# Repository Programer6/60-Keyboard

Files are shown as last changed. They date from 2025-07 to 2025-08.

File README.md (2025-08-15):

# 60%-Keyboard

Design for 60% keyboard with KMK firmware because I wanted a compact, minimal layout that saves space without sacrificing functionality. Full-sized keyboards felt bulky for my setup! This is my first keyboard, which I designed, so I wanted to keep think simple (no QMK, ofc)

# PCB
- The PCB's size is
- 61x key default 60% Layout!
- 2x Rotary Encoder
- 2 screens!

## Images

| Schematic                 |
| ------------------------- |
| Screenshot 2025-07-21 at 5 22 16 PM |
| Screenshot 2025-07-21 at 5 22 35 PM |

| PCB                   |
| --------------------- |
| Screenshot 2025-07-21 at 5 23 27 PM |

| Case                  |
| --------------------- |
| Screenshot 2025-08-15 at 2 25 50 PM |
| Screenshot 2025-08-04 at 1 43 16 PM
|

## BOM 
| Name | Qty | Final Price | Link |
| :--- | :-- | :--- | :--- |
| Cherry Profile PBT Keycaps | 1 | 17 | [Link](https://www.aliexpress.com/item/1005009109030179.html) |
| EC11s Rotary Encoder Code 5pin | | 8 | [Link](https://www.aliexpress.us/item/1005008610645902.html) |
| Knob | 2 | 6 |Preint Legend|
| OLED Module 1 | 1 | 4 | [Link](https://www.aliexpress.com/item/1005007038294972.html) |
| OLED Module 2 | 1 | 4 | |
| Gateron EF Grayish | 70 | 22 | Will buy myself [Link](https://www.aliexpress.us/item/1005006358112479.html) |
| Plate Mount Stabilizers | 9 | 9 | [Link](https://www.aliexpress.us/item/1005006528731543.html) |
| m3 16 mm | 10 | 3 | [Link](https://www.aliexpress.us/item/32810872544.html) |
| M3 25 mm | 10 | 3 | [Link](https://www.aliexpress.us/item/32810872544.html) |
| PCB | 44 | 40 | |
| Raspberry Pi Pico | 6 | 6 | [Link](https://www.aliexpress.us/item/1005007661444023.html) |
| Poron Gasket Strip | | 4 | [Link](https://www.aliexpress.com/item/1005003607093794.html) |
| M3(OD4.2mm) Heatset Insert | 25 | 2 | [Link](https://www.aliexpress.us/item/1005003582355741.html) |
| Keyboard Case | 1 | 5 | Print Legend |
| Diode 1N4148 Through | 80 | 1.3 | [Link](https://www.aliexpress.us/item/4000142272546.html) |

## Total Pricing
140$ - High estimate price rounded up! & buffer

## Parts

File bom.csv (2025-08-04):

Name | Qty | Final Price | Link
Cherry Profile PBT Keycaps | 1 | 17 | https://www.aliexpress.com/item/1005009109030179.html
EC11s Rotary Encoder Code 5pin |  | 8 | https://www.aliexpress.us/item/1005008610645902.html
Knob | 2 | 6 | https://www.aliexpress.us/item/1005008610645902.html
OLED Module 1 | 1 | 4 | https://www.aliexpress.com/item/1005007038294972.html
OLED Module 2 | 1 | 4
Gateron EF Grayish | 70 | 22 | https://www.aliexpress.us/item/1005006358112479.html
Plate Mount Stabilizers | 9 | 9 | https://www.aliexpress.us/item/1005006528731543.html
m3 16 mm | 10 | 3 | https://www.aliexpress.us/item/32810872544.html
M3 25 mm | 10 | 3 | https://www.aliexpress.us/item/32810872544.html
PCB | 44 | 40
Raspberry Pi Pico | 6 | 6 | https://www.aliexpress.us/item/1005007661444023.html
Poron Gasket Strip |  | 4 | https://www.aliexpress.com/item/1005003607093794.html
M3(OD4.2mm) Heatset Insert | 25 | 2 | https://www.aliexpress.us/item/1005003582355741.html
Keyboard Case | 1 | 5 | Print Legend
Diode 1N4148 Through | 80 | 1.3 | https://www.aliexpress.us/item/4000142272546.html

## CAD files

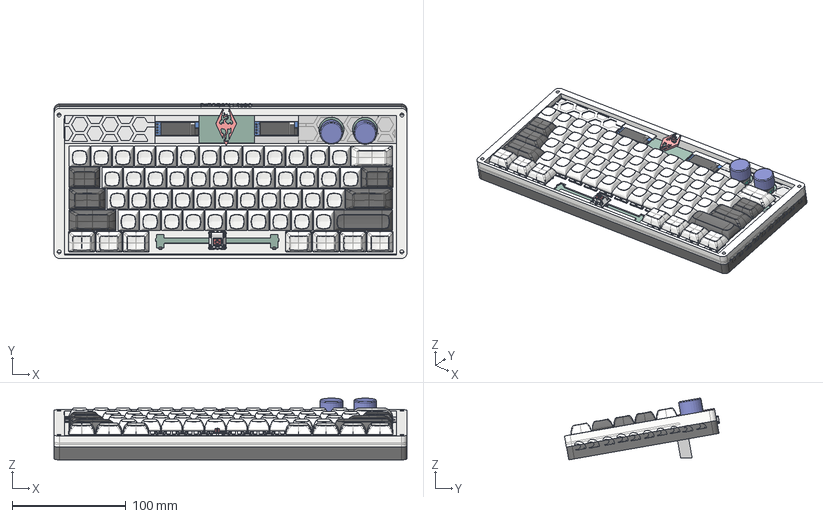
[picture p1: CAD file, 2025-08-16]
CAD/keyboard-v2 v4.step
310.0 x 136.3 x 54.2 mm
PCB, Raspberry Pi Pico-R3
MicroUSB Port, Raspberry Pi Pico-R3
RP2040 Microcontroller, Raspberry Pi Pico-R3
SW1, Tact Switch, Raspberry Pi Pico-R3
D1, Diode, Schottky, Raspberry Pi Pico-R3
D2, QSME-C194, LED, Raspberry Pi Pico-R3
L1, Inductor, Raspberry Pi Pico-R3
U2, RT6150B-33GQW, Buck Boost Converter, Raspberry Pi Pico-R3
U3, W25Q16JVUXIQ, Serial NOR Flash 16 Mbit, Raspberry Pi Pico-R3
Q1, MOSFET, DMG1012T, Raspberry Pi Pico-R3
X1, X12M000000S096, 12 Mhz Crystal Resonator, Raspberry Pi Pico-R3
SMD Resistor, Configurable, Raspberry Pi Pico-R3_R1
SMD Resistor, Configurable, Raspberry Pi Pico-R3_R2
SMD Resistor, Configurable, Raspberry Pi Pico-R3_R3
SMD Resistor, Configurable, Raspberry Pi Pico-R3_R4
SMD Resistor, Configurable, Raspberry Pi Pico-R3_R5
SMD Resistor, Configurable, Raspberry Pi Pico-R3_R6
SMD Resistor, Configurable, Raspberry Pi Pico-R3_R7
SMD Resistor, Configurable, Raspberry Pi Pico-R3_R8
SMD Resistor, Configurable, Raspberry Pi Pico-R3_R9
SMD Resistor, Configurable, Raspberry Pi Pico-R3_R10
SMD Resistor, Configurable, Raspberry Pi Pico-R3_R11
SMD Resistor, Configurable, Raspberry Pi Pico-R3_R12
SMD Resistor, Configurable, Raspberry Pi Pico-R3_R13
SMD Resistor, Configurable, Raspberry Pi Pico-R3_R14
SMD Resistor, Configurable, Raspberry Pi Pico-R3_R15
SMD Capacitor, Configurable, Raspberry Pi Pico-R3_C1
SMD Capacitor, Configurable, Raspberry Pi Pico-R3_C2
SMD Capacitor, Configurable, Raspberry Pi Pico-R3_C3
SMD Capacitor, Configurable, Raspberry Pi Pico-R3_C4
SMD Capacitor, Configurable, Raspberry Pi Pico-R3_C5
SMD Capacitor, Configurable, Raspberry Pi Pico-R3_C6
SMD Capacitor, Configurable, Raspberry Pi Pico-R3_C7
SMD Capacitor, Configurable, Raspberry Pi Pico-R3_C8
SMD Capacitor, Configurable, Raspberry Pi Pico-R3_C9
SMD Capacitor, Configurable, Raspberry Pi Pico-R3_C10
SMD Capacitor, Configurable, Raspberry Pi Pico-R3_C11
SMD Capacitor, Configurable, Raspberry Pi Pico-R3_C12
SMD Capacitor, Configurable, Raspberry Pi Pico-R3_C13
SMD Capacitor, Configurable, Raspberry Pi Pico-R3_C14
SMD Capacitor, Configurable, Raspberry Pi Pico-R3_C15
SMD Capacitor, Configurable, Raspberry Pi Pico-R3_C16
SMD Capacitor, Configurable, Raspberry Pi Pico-R3_C17
SMD Capacitor, Configurable, Raspberry Pi Pico-R3_C18
(Unsaved) (1) x 61
MX Mount v1 x 46
ѽת±ძǷ (1) x 2
Volume Knob x 2
OLED_0.91_128x32_2 x 2
Pin Header 4 x 1 TH 2.54mm Pitch x 2
RESC-0603 x 26
2SD0601A x 2
keycap5 x 2
R_0805_2012Metric x 2
QFN-28-1EP_6x6mm_P0.65mm_EP4.25x4.25mm
keycap x 7
DSA 2.75u
keycap3
keycap2 x 2
keycap4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

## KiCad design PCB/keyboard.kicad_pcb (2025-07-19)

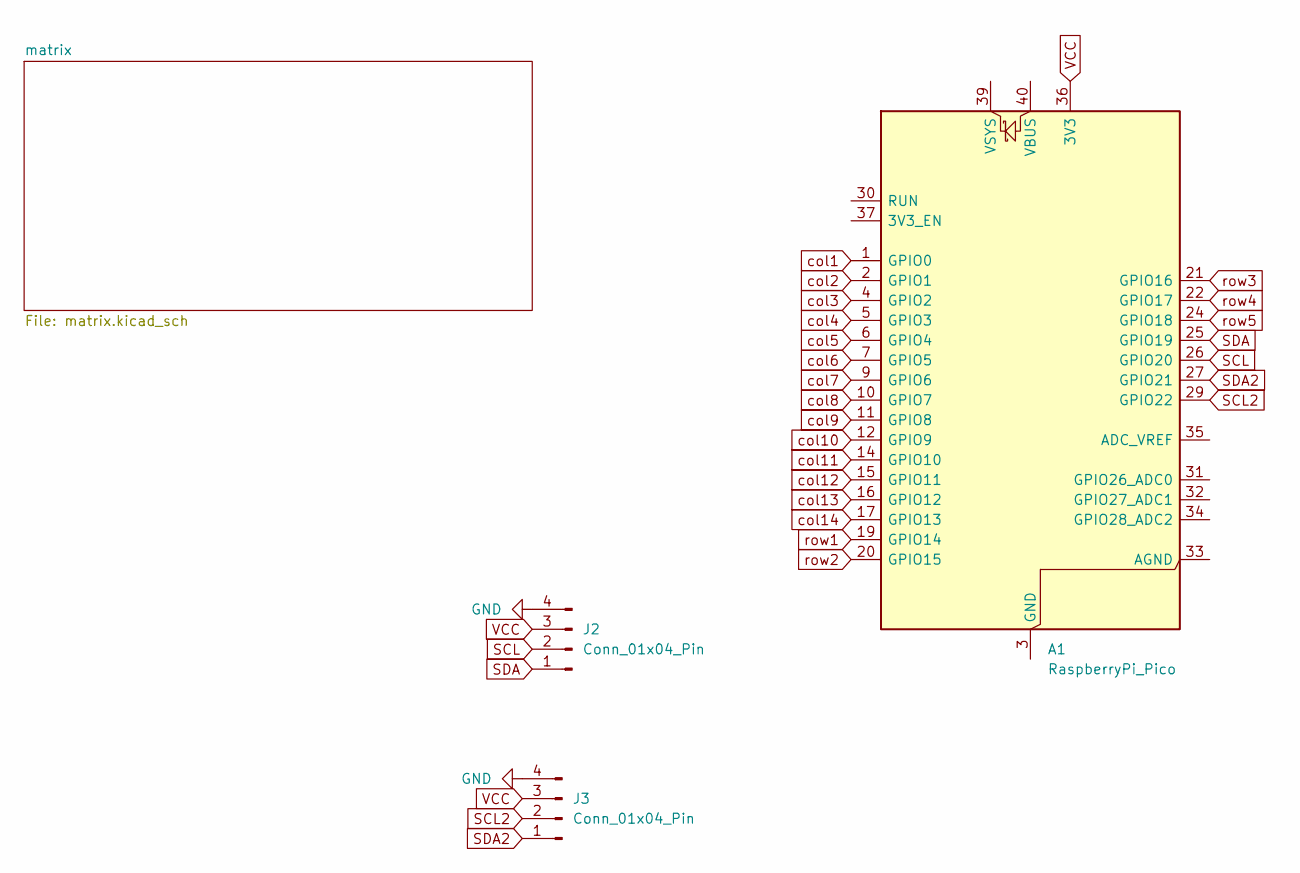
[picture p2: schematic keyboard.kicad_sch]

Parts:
A1: RaspberryPi_Pico; RaspberryPi_Pico_Common_Unspecified
J2, J3: Conn_01x04_Pin; SSD1306-0.91-OLED-4pin-128x32

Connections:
GND: J2.4, J3.4; also elsewhere on the board
unnamed: A1.3 (GND), A1.8 (GND), A1.13 (GND), A1.18 (GND), A1.23 (GND), A1.28 (GND), A1.38 (GND)
SCL: A1.26 (GPIO20), J2.2
SCL2: A1.29 (GPIO22), J3.2
SDA: A1.25 (GPIO19), J2.1
SDA2: A1.27 (GPIO21), J3.1
VCC: A1.36 (3V3), J2.3, J3.3
col1: A1.1 (GPIO0); also elsewhere on the board
col2: A1.2 (GPIO1); also elsewhere on the board
col3: A1.4 (GPIO2); also elsewhere on the board
col4: A1.5 (GPIO3); also elsewhere on the board
col5: A1.6 (GPIO4); also elsewhere on the board
col6: A1.7 (GPIO5); also elsewhere on the board
col7: A1.9 (GPIO6); also elsewhere on the board
col8: A1.10 (GPIO7); also elsewhere on the board
col9: A1.11 (GPIO8); also elsewhere on the board
col10: A1.12 (GPIO9); also elsewhere on the board
col11: A1.14 (GPIO10); also elsewhere on the board
col12: A1.15 (GPIO11); also elsewhere on the board
col13: A1.16 (GPIO12); also elsewhere on the board
col14: A1.17 (GPIO13); also elsewhere on the board
row1: A1.19 (GPIO14); also elsewhere on the board
row2: A1.20 (GPIO15); also elsewhere on the board
row3: A1.21 (GPIO16); also elsewhere on the board
row4: A1.22 (GPIO17); also elsewhere on the board
row5: A1.24 (GPIO18); also elsewhere on the board

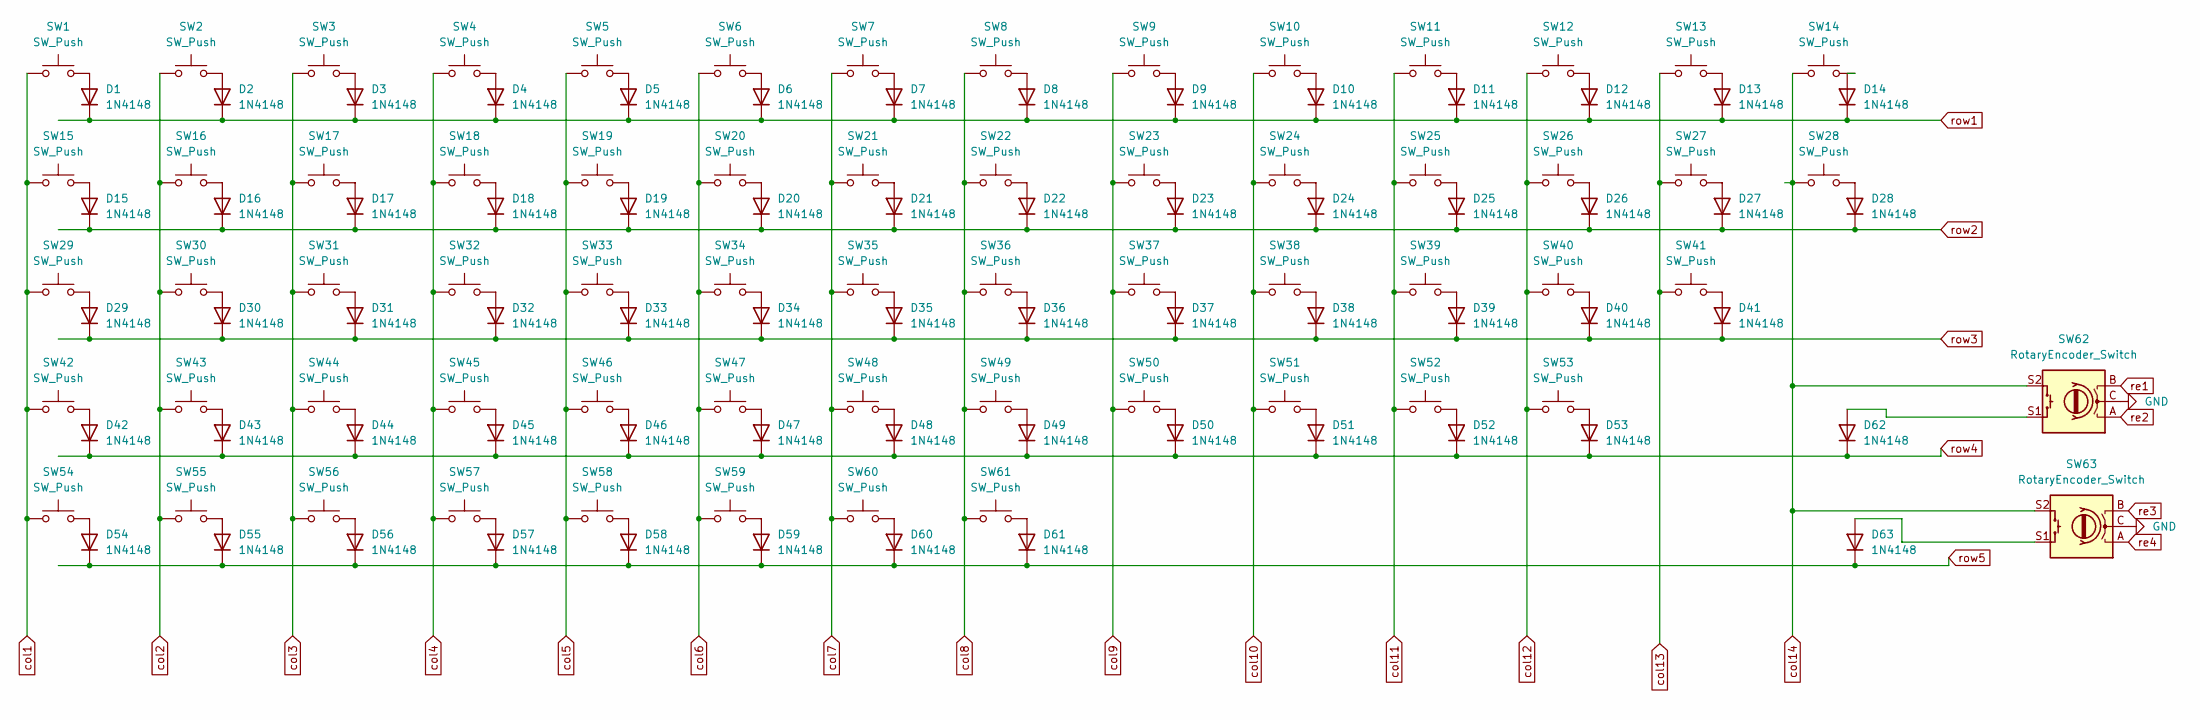
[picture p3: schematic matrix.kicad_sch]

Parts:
D1, D2, D3, D4, D5, D6, D7, D8, D9, D10, D11, D12, D13, D14, D15, D16, D17, D18, D19, D20, D21, D22, D23, D24, D25, D26, D27, D28, D29, D30, D31, D32, D33, D34, D35, D36, D37, D38, D39, D40, D41, D42, D43, D44, D45, D46, D47, D48, D49, D50, D51, D52, D53, D54, D55, D56, D57, D58, D59, D60, D61, D62, D63: 1N4148; D_DO-35_SOD27_P7.62mm_Horizontal
SW1, SW2, SW3, SW4, SW5, SW6, SW7, SW8, SW9, SW10, SW11, SW12, SW13, SW16, SW17, SW18, SW19, SW20, SW21, SW22, SW23, SW24, SW25, SW26, SW27, SW30, SW31, SW32, SW33, SW34, SW35, SW36, SW37, SW38, SW39, SW40, SW43, SW44, SW45, SW46, SW47, SW48, SW49, SW50, SW51, SW52: SW_Push; SW_Cherry_MX_1.00u_PCB
SW14: SW_Push; SW_Cherry_MX_2.00u_PCB
SW15, SW28: SW_Push; SW_Cherry_MX_1.50u_PCB
SW29: SW_Push; SW_Cherry_MX_1.75u_PCB
SW41, SW42: SW_Push; SW_Cherry_MX_2.25u_PCB
SW53: SW_Push; SW_Cherry_MX_2.75u_PCB
SW54, SW55, SW56, SW58, SW59, SW60, SW61: SW_Push; SW_Cherry_MX_1.25u_PCB
SW57: SW_Push; SW_Cherry_MX_6.25u_PCB
SW62, SW63: RotaryEncoder_Switch; RotaryEncoder_Alps_EC11E-Switch_Vertical_H20mm_CircularMoun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

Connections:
GND: SW62.C, SW63.C; also elsewhere on the board
unnamed: D1.2 (A), SW1.2
unnamed: D2.2 (A), SW2.2
unnamed: D3.2 (A), SW3.2
unnamed: D4.2 (A), SW4.2
unnamed: D5.2 (A), SW5.2
unnamed: D6.2 (A), SW6.2
unnamed: D7.2 (A), SW7.2
unnamed: D8.2 (A), SW8.2
unnamed: D9.2 (A), SW9.2
unnamed: D10.2 (A), SW10.2
unnamed: D11.2 (A), SW11.2
unnamed: D12.2 (A), SW12.2
unnamed: D13.2 (A), SW13.2
unnamed: D14.2 (A), SW14.2
unnamed: D15.2 (A), SW15.2
unnamed: D16.2 (A), SW16.2
unnamed: D17.2 (A), SW17.2
unnamed: D18.2 (A), SW18.2
unnamed: D19.2 (A), SW19.2
unnamed: D20.2 (A), SW20.2
unnamed: D21.2 (A), SW21.2
unnamed: D22.2 (A), SW22.2
unnamed: D23.2 (A), SW23.2
unnamed: D24.2 (A), SW24.2
unnamed: D25.2 (A), SW25.2
unnamed: D26.2 (A), SW26.2
unnamed: D27.2 (A), SW27.2
unnamed: D28.2 (A), SW28.2
unnamed: D29.2 (A), SW29.2
unnamed: D30.2 (A), SW30.2
unnamed: D31.2 (A), SW31.2
unnamed: D32.2 (A), SW32.2
unnamed: D33.2 (A), SW33.2
unnamed: D34.2 (A), SW34.2
unnamed: D35.2 (A), SW35.2
unnamed: D36.2 (A), SW36.2
unnamed: D37.2 (A), SW37.2
unnamed: D38.2 (A), SW38.2
unnamed: D39.2 (A), SW39.2
unnamed: D40.2 (A), SW40.2
unnamed: D41.2 (A), SW41.2
unnamed: D42.2 (A), SW42.2
unnamed: D43.2 (A), SW43.2
unnamed: D44.2 (A), SW44.2
unnamed: D45.2 (A), SW45.2
unnamed: D46.2 (A), SW46.2
unnamed: D47.2 (A), SW47.2
unnamed: D48.2 (A), SW48.2
unnamed: D49.2 (A), SW49.2
unnamed: D50.2 (A), SW50.2
unnamed: D51.2 (A), SW51.2
unnamed: D52.2 (A), SW52.2
unnamed: D53.2 (A), SW53.2
unnamed: D54.2 (A), SW54.2
unnamed: D55.2 (A), SW55.2
unnamed: D56.2 (A), SW56.2
unnamed: D57.2 (A), SW57.2
unnamed: D58.2 (A), SW58.2
unnamed: D59.2 (A), SW59.2
unnamed: D60.2 (A), SW60.2
unnamed: D61.2 (A), SW61.2
unnamed: D62.2 (A), SW62.S1
unnamed: D63.2 (A), SW63.S1
col1: SW1.1, SW15.1, SW29.1, SW42.1, SW54.1; also elsewhere on the board
col2: SW2.1, SW16.1, SW30.1, SW43.1, SW55.1; also elsewhere on the board
col3: SW3.1, SW17.1, SW31.1, SW44.1, SW56.1; also elsewhere on the board
col4: SW4.1, SW18.1, SW32.1, SW45.1, SW57.1; also elsewhere on the board
col5: SW5.1, SW19.1, SW33.1, SW46.1, SW58.1; also elsewhere on the board
col6: SW6.1, SW20.1, SW34.1, SW47.1, SW59.1; also elsewhere on the board
col7: SW7.1, SW21.1, SW35.1, SW48.1, SW60.1; also elsewhere on the board
col8: SW8.1, SW22.1, SW36.1, SW49.1, SW61.1; also elsewhere on the board
col9: SW9.1, SW23.1, SW37.1, SW50.1; also elsewhere on the board
col10: SW10.1, SW24.1, SW38.1, SW51.1; also elsewhere on the board
col11: SW11.1, SW25.1, SW39.1, SW52.1; also elsewhere on the board
col12: SW12.1, SW26.1, SW40.1, SW53.1; also elsewhere on the board
col13: SW13.1, SW27.1, SW41.1; also elsewhere on the board
col14: SW14.1, SW28.1, SW62.S2, SW63.S2; also elsewhere on the board
re1: SW62.B
re2: SW62.A
re3: SW63.B
re4: SW63.A
row1: D1.1 (K), D2.1 (K), D3.1 (K), D4.1 (K), D5.1 (K), D6.1 (K), D7.1 (K), D8.1 (K), D9.1 (K), D10.1 (K), D11.1 (K), D12.1 (K), D13.1 (K), D14.1 (K); also elsewhere on the board
row2: D15.1 (K), D16.1 (K), D17.1 (K), D18.1 (K), D19.1 (K), D20.1 (K), D21.1 (K), D22.1 (K), D23.1 (K), D24.1 (K), D25.1 (K), D26.1 (K), D27.1 (K), D28.1 (K); also elsewhere on the board
row3: D29.1 (K), D30.1 (K), D31.1 (K), D32.1 (K), D33.1 (K), D34.1 (K), D35.1 (K), D36.1 (K), D37.1 (K), D38.1 (K), D39.1 (K), D40.1 (K), D41.1 (K); also elsewhere on the board
row4: D42.1 (K), D43.1 (K), D44.1 (K), D45.1 (K), D46.1 (K), D47.1 (K), D48.1 (K), D49.1 (K), D50.1 (K), D51.1 (K), D52.1 (K), D53.1 (K), D62.1 (K); also elsewhere on the board
row5: D54.1 (K), D55.1 (K), D56.1 (K), D57.1 (K), D58.1 (K), D59.1 (K), D60.1 (K), D61.1 (K), D63.1 (K); also elsewhere on the board

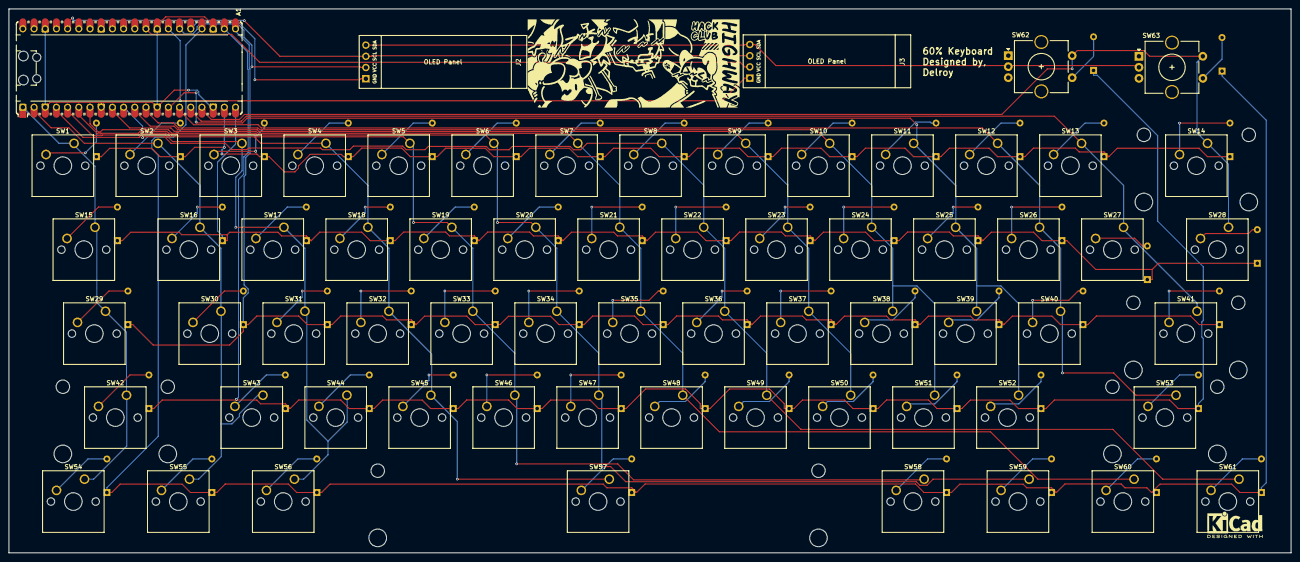
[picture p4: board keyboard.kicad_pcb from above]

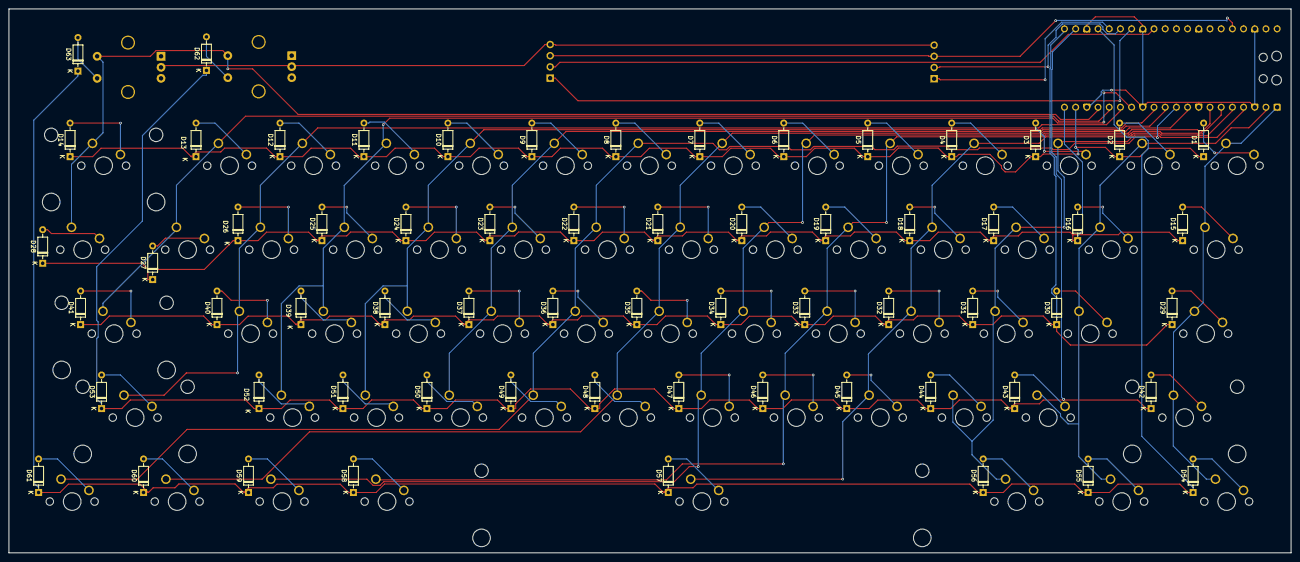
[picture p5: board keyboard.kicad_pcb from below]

Board: 2 copper layers, 290.9 x 123.4 mm, 129 parts (63 on the bottom side), 89 nets.

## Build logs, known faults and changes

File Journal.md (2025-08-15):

# 3D Printer Design: CAD & PCB Documentation
_Made by: @codelife / @programmer6_

| | |
|---|---|
| **Project Status** | Awaiting funding |
| **Total Time** |  30 Hours |
| **CAD Link** | https://a360.co/3TSTLiT |
| **Repository** | https://github.com/Programer6/60-Keyboard |

---

## June 18, 2025 - Schematic Design (3.5 hours)
I spent most of the day in KiCad laying out the schematic for the keyboard.

I designed a 5-row by 14-column key matrix. Each switch is paired with a 1N4148 diode to prevent "ghosting," an issue where unintended key presses are registered. I also added support for two rotary encoders (ideal for volume control or scrolling) and two I2C connectors for optional OLED screens. After double-checking all connections, the initial schematic is complete.

KiCad schematic of the key matrix with diodes

The plan is to use a Raspberry Pi Pico as the microcontroller. It's powerful, affordable, and has excellent community support, particularly with the KMK firmware I intend to use.

KiCad schematic of the Raspberry Pi Pico and its connections

Here are the other detailed views from the schematic:

KiCad schematic showing rotary encoder connections
KiCad schematic showing I2C connector details
KiCad schematic showing another view of the key matrix
KiCad schematic overview

---
## June 19, 2025 - Initial Component Placement (2.5 hours)
Started the initial placement of components on the PCB. I held off on routing the traces because I realized there were still a few things to update in the schematic, and I also want to add some custom silkscreen art.

Initial component placement in KiCad's PCB editor
Close-up of initial component placement

---
## June 20, 2025 - Schematic Revision & GPIO Expander (3 hours)
I started laying out the PCB today and immediately ran into a problem. While the Pi Pico has a lot of GPIO pins, my initial design used almost all of them, which was going to make routing the board a nightmare.

To fix this, I revised the schematic to include an **MCP23017 GPIO expander**. This significantly reduces the number of pins required on the Pico, freeing up space and making the layout much cleaner.

While I was at it, I also fixed the I2C connections. Thanks to a suggestion from **LemonGravy**, I've consolidated the entire I2C bus. The GPIO expander and the two OLED screen connectors (J1, J2) now share the same SCL and SDA lines, with the proper pull-up resistors added.

Revised schematic with the MCP23017 GPIO expander

---
## June 21, 2025 - PCB Routing (5 hours)
I spent the entire day routing the PCB in KiCad. The decision to use a GPIO expander yesterday really paid off, as it made the routing process much more manageable and resulted in a cleaner layout.

Here is the fully routed board:
Fully routed PCB in KiCad

---
## June 22, 2025 - 3D Visualization & Case Design (7 hours total)

#### 3D Models in KiCad (3 hours)
I added 3D models for all the components in KiCad. This provides a realistic 3D preview of the finished PCB, which is crucial for verifying component placement and clearances before designing the case.
3D view of the PCB in KiCad with all component models

#### 3D Printed Case Design (4 hours)
After finalizing the PCB, I exported the 3D model from KiCad and imported it into Fusion 360. I designed a simple and functional two-part case: a main body that holds the PCB and a top frame that acts as a switch plate and bezel.
3D model of the keyboard case designed in Fusion 360

---
## June 23, 2025 - Firmware and Documentation (8 hours total)

#### KMK Firmware (5 hours)
I spent the day writing the firmware for the keyboard using KMK, a powerful CircuitPython-based firmware. I configured the key matrix, rotary encoders, and the I2C bus for the OLED screens. The initial firmware is now functional and ready for flashing.

#### Documentation & BOM (3 hours)
Finalized the project documentation by creating the Bill of Materials (BOM), organizing all progress logs and images, and writing this README file to document the entire process.

Updated Keyboard after getting rejected:
Screenshot 2025-08-04 at 1 51 33 PM

 #### Got unofficial review from Taran the Idiot
-  Production folder had a file named production with no file type which I forgot to add so updated
-  Update BOM to use knob from printing Legion
- hugged the oleds a bit more in cad
- Update the journal and image in repo with the changes made!

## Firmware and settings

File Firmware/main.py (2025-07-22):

import board
import busio
import displayio
import terminalio
from adafruit_display_text import label
from adafruit_displayio_ssd1306 import SSD1306

from kmk.kmk_keyboard import KMKKeyboard
from kmk.keys import KC
from kmk.scanners import DiodeOrientation
from kmk.modules.layers import Layers
from kmk.modules.encoders import Encoders
from kmk.extensions.mcp23017 import MCP23017
from kmk.extensions.media_keys import MediaKeys
from kmk.extensions import Extension

class OledScreen(Extension):
    def __init__(self, i2c_bus):
        displayio.release_displays()

        try:
            display_bus_one = displayio.I2CDisplay(i2c_bus, device_address=0x3C)
            self.display_one = SSD1306(display_bus_one, width=128, height=32)
            self.group_one = displayio.Group()
            self.display_one.show(self.group_one)

            self.layer_label = label.Label(terminalio.FONT, text="Layer: 0", x=2, y=5)
            self.caps_label = label.Label(terminalio.FONT, text="CAPS", x=2, y=25)
            self.num_label = label.Label(terminalio.FONT, text="NUM", x=42, y=25)
            
            self.group_one.append(self.layer_label)
            self.group_one.append(self.caps_label)
            self.group_one.append(self.num_label)
        except (ValueError, RuntimeError):
            self.display_one = None

        try:
            display_bus_two = displayio.I2CDisplay(i2c_bus, device_address=0x3D)
            self.display_two = SSD1306(display_bus_two, width=128, height=64)
            self.group_two = displayio.Group()
            self.display_two.show(self.group_two)

            logo_label = label.Label(terminalio.FONT, text="-- My Keeb --", scale=2, x=10, y=30)
            self.group_two.append(logo_label)
        except (ValueError, RuntimeError):
            self.display_two = None

    def on_state_change(self, key, is_pressed, int_coord):
        if self.display_one:
            self.layer_label.text = f"Layer: {key.active_layers[0]}"
            self.caps_label.hidden = not key.caps_lock_status
            self.num_label.hidden = not key.num_lock_status

keyboard = KMKKeyboard()

keyboard.modules.append(Layers())
keyboard.modules.append(Encoders())
keyboard.extensions.append(MediaKeys())

i2c = busio.I2C(scl=board.GP9, sda=board.GP8)

oled_ext = OledScreen(i2c_bus=i2c)
keyboard.extensions.append(oled_ext)

mcp23017_ext = MCP23017(
    i2c=i2c,
    device_address=0x20,
    gp_int_a=None,
    gp_int_b=None,
)
keyboard.extensions.append(mcp23017_ext)

keyboard.col_pins = (
    board.GP0, board.GP1, board.GP2, board.GP3,
    board.GP4, board.GP5, board.GP6, board.GP7,
    board.GP10, board.GP11, board.GP12, board.GP13,
    board.GP14, board.GP15,
)
keyboard.row_pins = (
    mcp23017_ext.get_pin('GPB0'), mcp23017_ext.get_pin('GPB1'),
    mcp23017_ext.get_pin('GPB2'), mcp23017_ext.get_pin('GPB3'),
    mcp23017_ext.get_pin('GPB4'),
)
keyboard.diode_orientation = DiodeOrientation.COL2ROW

keyboard.encoder_handler.pins = (
    (board.GP16, board.GP17, None),
    (board.GP18, board.GP19, None),
)

FN = KC.MO(1)
_______ = KC.TRNS

keyboard.keymap = [
    [
        KC.GRAVE, KC.N1,    KC.N2,   KC.N3,    KC.N4,   KC.N5,   KC.N6,    KC.N7,   KC.N8,   KC.N9,    KC.N0,   KC.MINS,  KC.EQL,   KC.BSPC,
        KC.TAB,   KC.Q,     KC.W,    KC.E,     KC.R,    KC.T,    KC.Y,     KC.U,    KC.I,    KC.O,     KC.P,    KC.LBRC,  KC.RBRC,  KC.BSLS,
        KC.CAPS,  KC.A,     KC.S,    KC.D,     KC.F,    KC.G,    KC.H,    KC.J,    KC.K,    KC.L,     KC.SCLN, KC.QUOT,  KC.ENT,   KC.NO,
        KC.LSFT,  KC.Z,     KC.X,    KC.C,     KC.V,    KC.B,    KC.N,    KC.M,    KC.COMM, KC.DOT,   KC.SLSH, KC.RSFT,  KC.UP,    KC.NO,
        KC.LCTL,  KC.LGUI,  KC.LALT, KC.SPC,   KC.NO,   KC.NO,   KC.NO,   KC.RALT, KC.RGUI, FN,       KC.LEFT, KC.DOWN,  KC.RGHT,  KC.NO,
    ],
    [
        KC.ESC,   KC.F1,    KC.F2,   KC.F3,    KC.F4,   KC.F5,   KC.F6,    KC.F7,   KC.F8,   KC.F9,    KC.F10,  KC.F11,   KC.F12,   KC.DEL,
        _______,  _______,  KC.UP,   _______,  _______, _______, _______, _______, KC.NLCK, KC.PSCR,  _______, _______,  _______,  KC.MUTE,
        _______,  KC.LEFT,  KC.DOWN, KC.RGHT,  _______, _______, _______, _______, _______, _______,  _______, _______,  KC.MPLY,  KC.NO,
        _______,  _______,  _______, _______,  _______, _______, _______, _______, KC.VOLD, KC.VOLU,  KC.MPRV, KC.MNXT,  _______,  KC.NO,
        _______,  _______,  _______, _______,  _______, _______, _______, _______, _______, _______,  _______, _______,  _______,  KC.NO,
    ]
]

keyboard.encoder_handler.map = (
    ( (KC.VOLD, KC.VOLU), (KC.MW_DN, KC.MW_UP) ),
    ( (KC.PGDN, KC.PGUP), (KC.NO, KC.NO) ),
)

if __name__ == '__main__':
    keyboard.go()
